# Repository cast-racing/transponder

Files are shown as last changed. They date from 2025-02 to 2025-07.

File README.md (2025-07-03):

# Transponder

Transponder between cars for the Indy Autonomous Challenge.

Features
- Arduino based
- ROS2 node example
- Powered via PoE

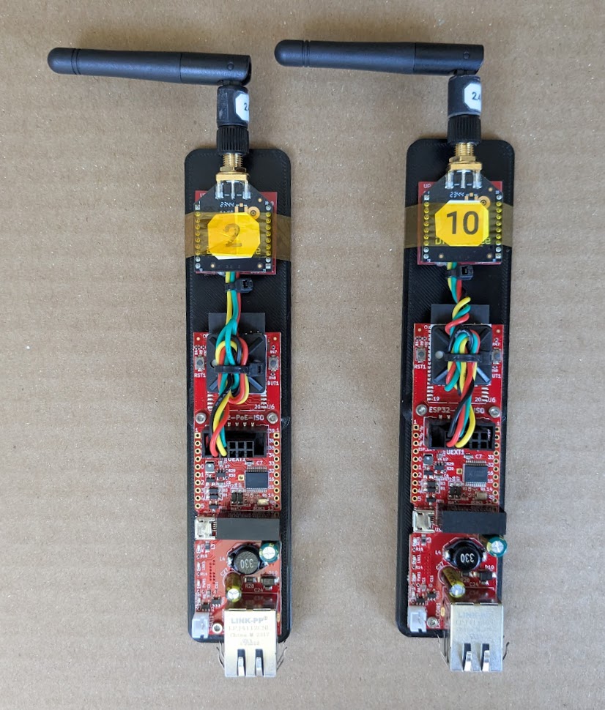
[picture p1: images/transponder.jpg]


## Theory of Operation
The ESP32-PoE-ISO listens to UDP packets published from the ROS2 node `transponder2ros_node`.
These are then packaged with a header and a checksum and sent out as serial data over the xbee network to all the available nodes.
The ESP32-PoE-ISO takes any received packets over the xbee network, checks their integrity, and converts them back into UDP packets, and forwards them back to the `transponder2ros_node`.
The node then publishes the data out as a `transponder_msgs::msg::Transponder` onto the ROS2 network.

Each air packet is about 40 bytes long, so the network can handle about `XXXXX, to test in real world conditions` packets/sec between all nodes.
The data format is designed to look like a GPS packet with some additional information, so make sure to read the comments in the `.msg` file to ensure your data is in the correct units (and scales).
All data should be referenced from the centre of the rear axle and the time reference is UTC.

## Installation
### ROS2
All dependencies on the ROS2 side can be installed via rosdep.
From your main workspace folder, run `rosdep install --from-paths src --ignore-src -r -y`.
If you have trouble with finding geographiclibs, debian/ubuntu installs `FindGeographicLib.cmake` in a non-standard location, but this should be covered in the `CMakeLists.txt` file.

### Arduino
The Arduino code is only required to update the transponder firmware.
See the [Arduino README.md](arduino/README.md) for installation instructions.

### XBee
[XTCU](https://www.digi.com/products/embedded-systems/digi-xbee/digi-xbee-tools/xctu) is used to configure the XBee.  This should only be required once.

## Component Setup
See the individual README.md files in each folder for more information - [ESP32-PoE-ISO (Arduino)](arduino/README.md) / [ROS](ros/README.md) / [XBee](xbee/README.md) / [Hardware](hardware/README.md).

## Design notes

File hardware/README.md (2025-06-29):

# Transponder Hardware

## Bill of Materials
- Compute
  - Olimex ESP32-PoE-ISO
    - https://www.digikey.com/en/products/detail/olimex-ltd/ESP32-POE-ISO/10258716
- Radio
  - Xbee radio
    - https://www.digikey.com/en/products/detail/digi/XB3-24Z8ST/8130935
  - Xbee breakout
    - https://www.digikey.com/en/products/detail/sparkfun-electronics/BOB-08276/5318741
  - Xbee headers
    - https://www.digikey.com/en/products/detail/adafruit-industries-llc/366/5629440
  - Xbee to USB breakout (recommended for programming Xbees)
    - https://www.digikey.com/en/products/detail/sparkfun-electronics/11812/5762455
- Antennas
  - Antenna (small)
    - https://www.digikey.com/en/products/detail/te-connectivity-linx/ANT-2-4-LCW-RPS/9607800
  - Antenna (large)
    - https://www.digikey.com/en/products/detail/taoglas-limited/FW-24-SMA-M/7035228
- Extension Cables
  - 250 mm (9.8") RP-SMA to RP-SMA
    - https://www.digikey.com/en/products/detail/sparkfun-electronics/22037/21443079
  - 1 m (3'3") RP-SMA to RP-SMA
    - https://www.digikey.com/en/products/detail/sparkfun-electronics/22036/21443073

## Wiring
26 AWG is a good choice for wiring guage, however down to 30 AWG will work fine too.
You can use 0.1" headers (female dupont) for connecting to the ESP32-PoE-ISO.

| Colour  | Voltage | ESP32-PoE-ISO | XBee |
| --- | --- | --- | ---- |
| Red | 3V3 | +3.3V (Pin 1) | VCC  |
| Black | GND | GND (Pin 2) | GND  |
| Yellow  | 3V3 | U1TXD (Pin 3) | DIN  |
| Green | 3V3 | U1RXD (Pin 4) | DOUT |

> **Warning:** Different XBee breakout boards may take different voltages in or have slightly different locations for each of the pins.
Make sure to double check your wiring and use a multimeter before first connecting everything.

Finally, make sure to hotglue down the wires to help load alleviate the solder joints.

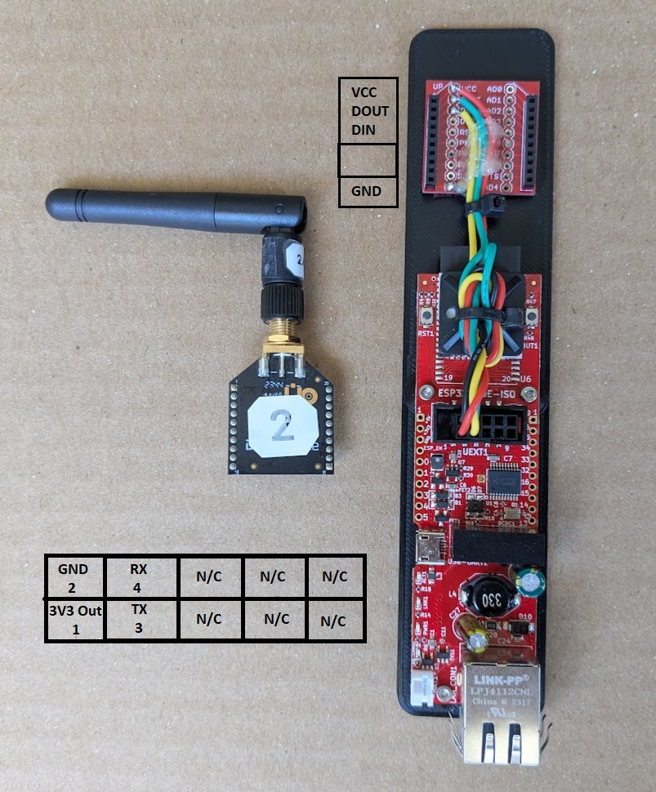
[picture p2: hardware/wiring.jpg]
wiring


## Assembly
The attached STL (Solidworks files included) can be 3D printed to give a mount that can be used to join the parts together.
- Three [M2x6 socket head cap screws](https://www.mcmaster.com/91292a831/) are used for mounting the ESP32-PoE-ISO to the board.
  - You could probably also use double-sided tape and a cable tie, but things might get a little warm.
- Double-sided tape is used to mount the XBee to the board
  - Hold the XBee to the board by wrapping tape around.
- Clean up your cables.
  - A 0.75" x 0.75" cable tie mount works well
  - Don't pull the cables too tightly

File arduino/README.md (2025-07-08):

# Transponder (Arduino)

The ESP32-PoE-ISO is programmed using Arduino, and is required to set up the IP addresses.  Flashing should only be required once and then only during message version updates.

## Installation
### Linux
- Download Arduino CLI (or use an existing Arduino install)
  - Follow the instructions at https://arduino.github.io/arduino-cli/1.2/installation/, or,
  - `curl -fsSL https://raw.githubusercontent.com/arduino/arduino-cli/master/install.sh | sh`
    - Move the file `bin/arduino-cli` to `/usr/bin`
- Install board support (search cores with  `arduino-cli board search olimex`)
  - `arduino-cli core update-index`
  - `arduino-cli config set network.connection_timeout 600s`
  - `arduino-cli core install esp32:esp32`

### Windows
Windows doesn't support arduino-cli, so there's a little more manual setup requried.
- Download Arduino IDE from https://www.arduino.cc/en/software
- Install the ESP32 Core
  - `Tools > Board > Board Manager` and search for esp32
  - Install `esp32 by Espressif Systems`
- Under `Select Board > Select Other Board and Port`
  -  Boards: `OLIMEX ESP32-POE-ISO`
  -  Ports: Select the correct port for the Transponder (plugged in via USB)
-  Modify the code as below, then upload using the arrow in the circle (top left-hand corner near the tick).

You can see the debug messages through the Serial Monitor
- `Tools > Serial Monitor`

## Flashing the Firmware
- Change the network settings in `arduino/transponder/transponder.ino` to match your network
  - Comment / uncomment the `#define` at the top of the script to match your setup
    - `#define TRANSPONDER_IP "10.42.7.61"` is the IP address of your transponder
    - `#define COMPUTER_IP "10.42.7.4"` is the IP address of your computer's network interface
    - If your car is not listed, submit a PR to get it added
- Upload using the script `./compile_and_upload`.  Check the devices match (defaults to `/dev/ttyUSB0`)
  - Alternatively use the Arduino IDE and upload as `OLIMEX ESP32-POE-ISO` board type.
    - Requires the [Arduino-ESP32 package](https://docs.espressif.com/projects/arduino-esp32/en/latest/installing.html).
- The USB connection provides debug information at a baud rate of 115200 including IPs and received information.

## Debugging
The main way to debug is to get the transponder to print when it receives packets from either the UDP or XBee ports.
These messages can be viewed by connecting to the uUSB port on the transponder and connecting via a serial port at 115200 baud.
On a heavily loaded network, the debugging will likely overload the serial port, so the messages are disabled by default.
To enable the debug messages, set `const bool print_debug_ = 0;` to `1` in `transponder.ino`, an re-upload the firmware.

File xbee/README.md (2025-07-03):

# XBee

The XBee is used to communicate between the nodes.

## Configuration
- Download XCTU from
- Connect to the xbee, and apply the profile in `xbee/iac_default.pro`.
  - Update the parameters and the firmware.  If it doesn't update the firmware, apply the settings, and upload the profile again. 
  - Remember to click the `Write` button!
- Power cycle the XBee.  The baud rate will be switched to 57600 baud.
- Connect again and set the `Node Identifier` to the car number for easy remote identification.
  - Remember to click the `Write` button.

## Images
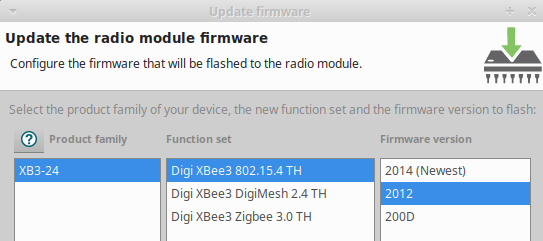
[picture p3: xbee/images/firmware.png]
firmware


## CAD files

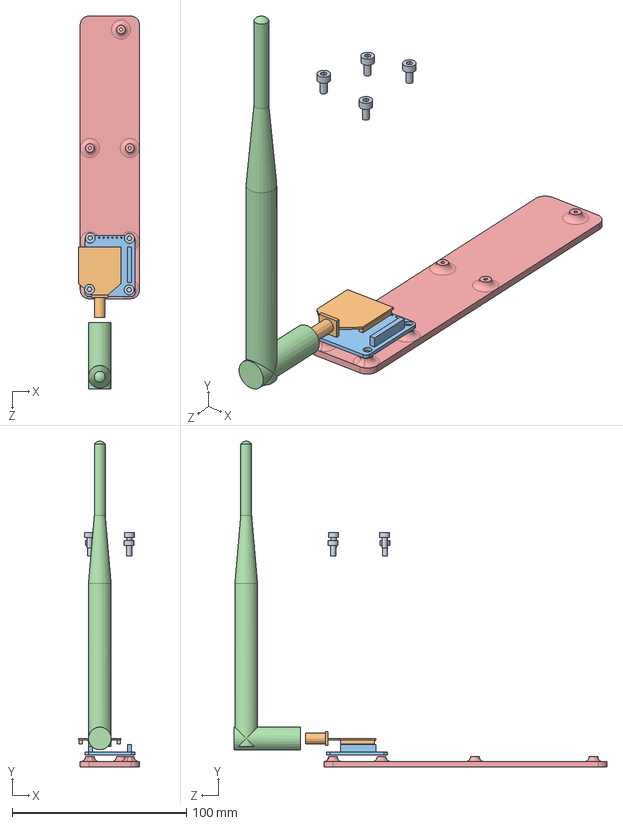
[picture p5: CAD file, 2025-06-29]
hardware/cad/transponder_assembly.SLDASM
35.0 x 186.7 x 213.8 mm
esp32-poe-iso_mount
2.4GHz_antenna_long
xbee_explorer_adaptor
xbee3
M3x6 x 4

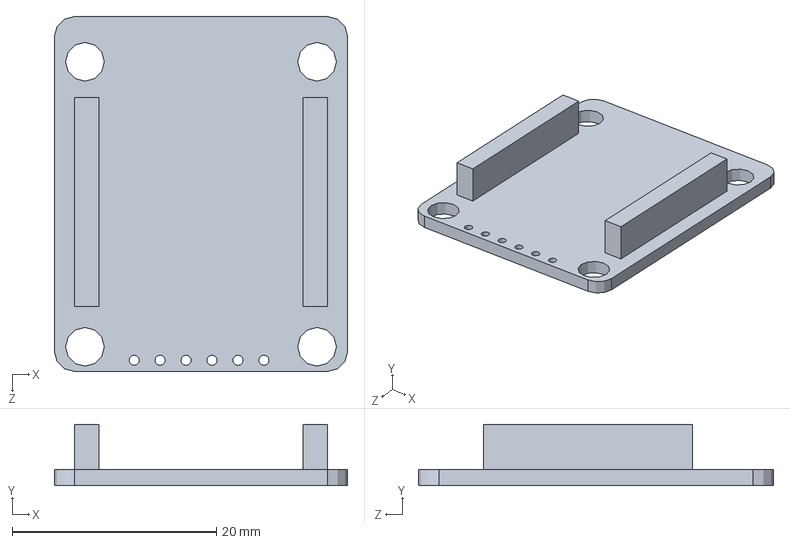
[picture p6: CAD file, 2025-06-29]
hardware/cad/xbee_explorer_adaptor.SLDPRT
28.8 x 5.99 x 34.8 mm

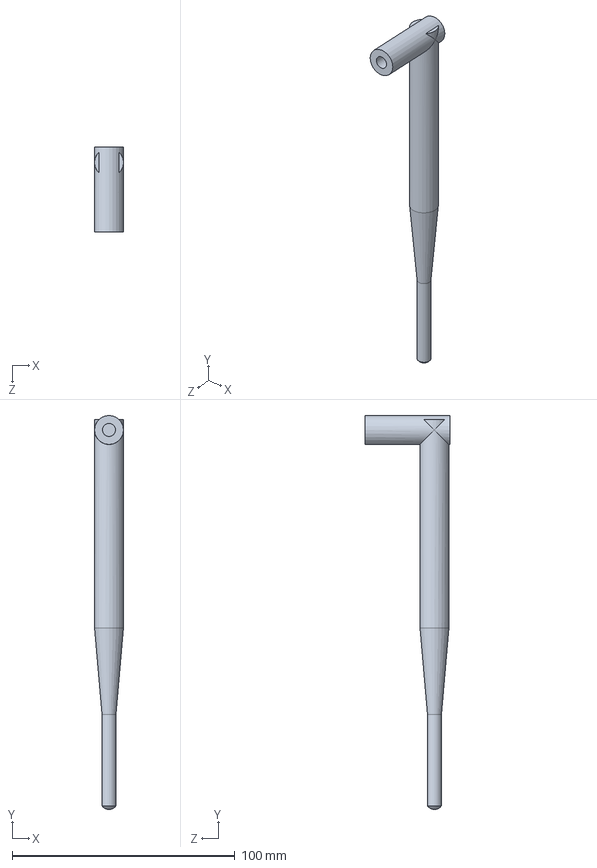
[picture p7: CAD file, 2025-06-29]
hardware/cad/2.4GHz_antenna_long.SLDPRT
13.0 x 176.9 x 38.2 mm

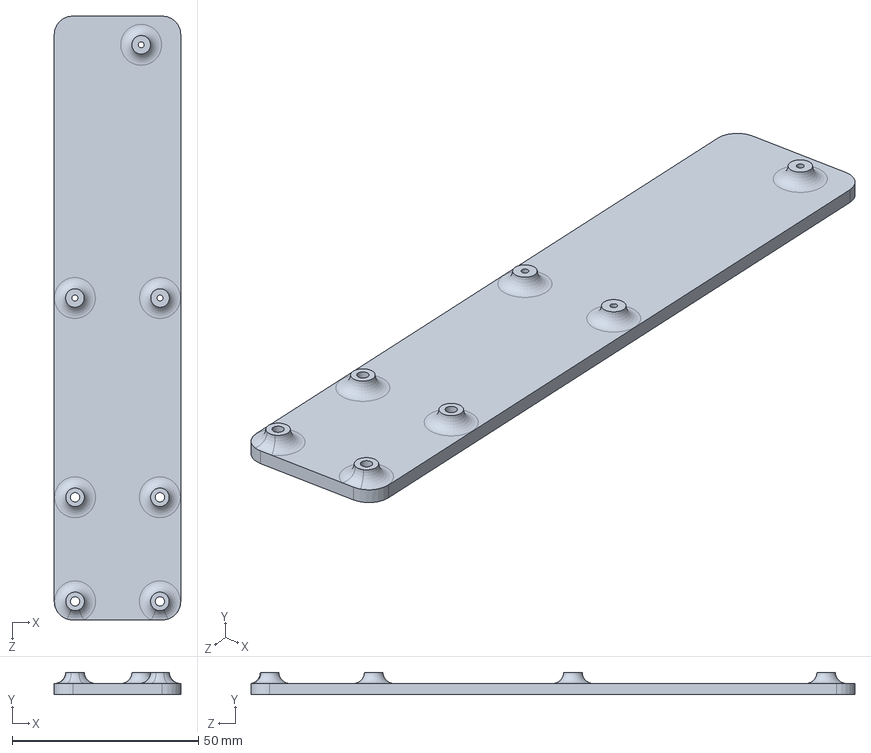
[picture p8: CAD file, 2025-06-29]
hardware/cad/esp32-poe-iso_mount.SLDPRT
34.0 x 6.00 x 162.1 mm

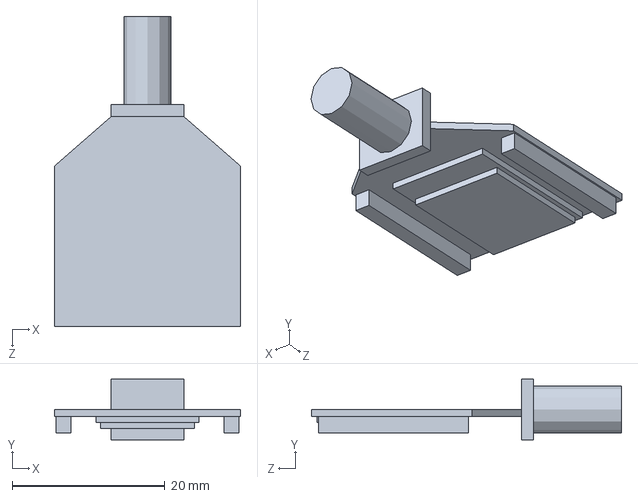
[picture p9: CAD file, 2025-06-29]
hardware/cad/xbee3.SLDPRT
24.4 x 7.93 x 40.6 mm

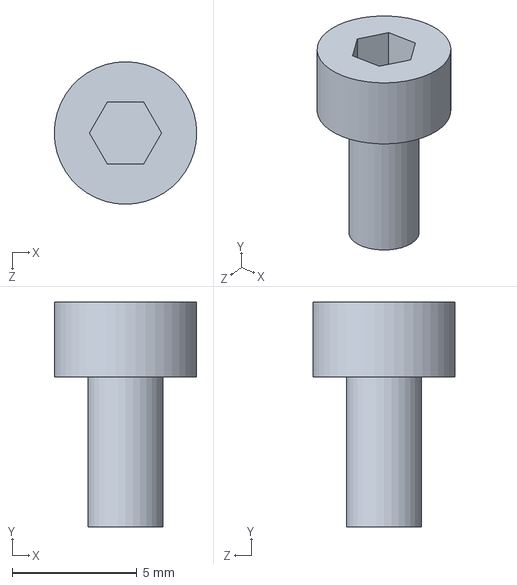
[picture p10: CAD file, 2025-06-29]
hardware/cad/M3x6.SLDPRT
5.70 x 9.00 x 5.70 mm

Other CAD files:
hardware/cad/esp32-poe-iso_mount.STL

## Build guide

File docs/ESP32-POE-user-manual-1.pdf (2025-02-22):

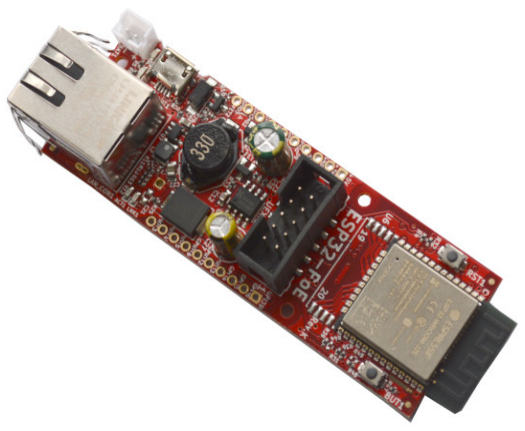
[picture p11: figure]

# ES32-POE ESP32-POE-ISO

# User Manual

Document revision 2.2.

## June 2024

# www.olimex.com

## Table of Contents

## 1. Introduction to ESP32-POE and ESP32-POE-ISO

ESP32-PoE (https://www.olimex.com/Products/IoT/ESP32/ESP32-POE/open-source-hardware) and ESP32-PoE-ISO (https://www.olimex.com/Products/IoT/ESP32/ESP32-POE-ISO/open-source-hardware) are ESP32-powered Wi-Fi/Bluetooth/Ethernet development boards with Power-Over-Ethernet feature. The boards are the perfect addition to any project that requires extra connectivity.
The PoE is currently handled by TPS2375/6 chip (Si3402-B in older revisions) that is IEEE 802.3af-compliant, including pre-standard (legacy) PoE support.
The PoE powering requires at least 37V DC to operate successfully. The board can takes power from the Ethernet cable and can be expanded with sensors and more. Perfect solution for Internet-of-Things projects.
Both ESP32-POE and ESP32-POE-ISO are mature, popular, and well-known products, with wide software support.
+ Important notice: ESP32-PoE (https://www.olimex.com/Products/IoT/ESP32/ESP32-POE/open-source-hardware) has no galvano isolation of Ethernet's power supply, when you program the board via the micro USB connector the Ethernet cable should be disconnected (if you have power over the Ethernet enabled)! Consider using Olimex USB-ISO (https://www.olimex.com/Products/USB-Modules/USB-ISO/) to protect your computer and board from accidental short circuits. Also consider using Olimex ESP32-PoE-ISO (https://www.olimex.com/Products/IoT/ESP32/ESP32-POE-ISO/open-source-hardware) board instead since it is insulated.

## 1.1. ESP32-POE features

- ESP32-WROOM-32E module WiFi + Bluetooth ® + Bluetooth LE module from Espressif Inc (ESP32-WROOM-32UE or ESP32-WROVER-E/IE depending on variant)
- ESP32-WROOM-32E/UE have 4MB flash and 520 KB SRAM
- ESP32-WROVER-E/IE have 4MB Flash 520KB SRAM and 8MB PSRAM
- High reliable industrial grade (-40+85C) variant available (-IND)
- CE-RED and LVD certification
- Original design by OLIMEX Ltd
- Power Over Ethernet negotiation circuit, 802.3-compliant, with minimum operating voltage of 37VDC
- DC-DC converter with 3A at 5V output
- Li-Po battery charger and connector
- Battery level monitor pin on ADC
- External power supply detection pin on ADC
- UEXT connector (https://www.olimex.com/Products/Modules/UEXT/)
- User button
- Reset button
- Micro USB with programmer for ESP32 programming
- MicroSD card
- Two extension connectors 0.1" step spaced at 1"
- PCB dimensions: (80 x 28)mm ~ (3.15 x 1.1)"

## 1.2. ESP32-POE-ISO features

- ESP32-WROOM-32E WiFi + Bluetooth ® + Bluetooth LE module by Espressif Inc (ESP32-WROOM-32UE or ESP32-WROVER-E/IE depending on variant)
- ESP32-WROOM-32E and ESP32-WROOM-32UE have 4MB flash and 520 KB SRAM
- ESP32-WROVER-E/IE have 4MB Flash 520KB SRAM and 8MB PSRAM
- Power Over Ethernet negotiation circuit 802.3 compliant, with minimum operating voltage of 35VDC
- High reliable industrial grade -40+85C available (-IND)
- CE-RED and LVD certification
- Original design by OLIMEX Ltd
- Low power design – 200uA consumption in deep sleep
- Ethernet 100Mb interface with IEEE 802.3 PoE support
- 3000VDC galvanic insulation between the PoE Ethernet part and board's power supply circuit Micro USB connector for ESP32 programming
- MicroSD card working in 1 bit mode
- LiPo battery charger with LiPo battery connector
- Battery level monitor pin on ADC
- External power supply detection pin on ADC
- DC-DC 2W 5V/400mA
- UEXT connector (https://www.olimex.com/Products/Modules/UEXT/)
- User button
- Reset button
- Two extension connectors, 0.1" step spaced at 1"
- PCB dimensions: (98x28)mm ~ (3.8x1)"

## 1.3. PoE standard

ESP32-POE and ESP32-POE-ISO are compliant with the IEEE 802.3af PoE standard and provide up to 15.4 W of DC power (minimum 37V DC and 350 mA). Only 12.95 W are assured to be available at the powered device as some power dissipates in the cable.

ESP32-POE-ISO has 2W DC-DC 5V-5V insulation converter which prevents electrical influence between different sources of power but limits the power usage to 2W only!

## 1.4. The difference between ESP32-POE and ESP32-POE-ISO:

ESP32-POE is not galvanically isolated which means that it’s not safe to connect it to other devices which use non isolated power supply while it is powered. It should have only one power supply and one ground attached to it at a time.
+ This means YOU SHOULD NOT CONNECT ESP32-POE to computer’s USB port while it is powered by Ethernet POE!!! If you connect USB while ESP32-POE is powered by Ethernet you will damage the board or your computer or both. This will also void the warranty!

ESP32-POE-ISO, on the other hand comes with 3000VDC galvanic insulation between the Ethernet POE part and ESP32 power supply, so there is no problem to connect to USB and program or debug while the board is also powered from a PoE source.

## 1.5. The differences between different variants of ESP32-POE and ESP32-POE-ISO:

ESP32-POE (https://www.olimex.com/Products/IoT/ESP32/ESP32-POE/open-source-hardware) and ESP32-POE-ISO (https://www.olimex.com/Products/IoT/ESP32/ESP32-POE-ISO/open-source-hardware) are the base versions with ESP32-WROOM module with 4MB flash memory and nothing extra.

ESP32-POE-EA (https://www.olimex.com/Products/IoT/ESP32/ESP32-POE-EA/open-source-hardware) and ESP32-POE-ISO-EA (https://www.olimex.com/Products/IoT/ESP32/ESP32-POE-ISO-EA/open-source-hardware) have ESP32-WROOM-32UE module with U.FL connector and external antenna attached.

ESP32-POE-IND (https://www.olimex.com/Products/IoT/ESP32/ESP32-POE-IND/open-source-hardware) and ESP32-POE-EA-IND (https://www.olimex.com/Products/IoT/ESP32/ESP32-POE-EA-IND/open-source-hardware) and ESP32-POE-ISO-IND (https://www.olimex.com/Products/IoT/ESP32/ESP32-POE-ISO-IND) and ESP32-POE-ISO-EA-IND (https://www.olimex.com/Products/IoT/ESP32/ESP32-POE-ISO-EA-IND) use industrial grade components suitable for -40+85C operating temperature.

ESP32-POE-WROVER (https://www.olimex.com/Products/IoT/ESP32/ESP32-POE-WROVER/open-source-hardware) and ESP32-POE-ISO-WROVER (https://www.olimex.com/Products/IoT/ESP32/ESP32-POE-ISO-WROVER) comes with ESP32-WROVER-E chip with 4MB flash and 8MB PSRAM, while ESP32-POE-WROVER-EA (https://www.olimex.com/Products/IoT/ESP32/ESP32-POE-WROVER-EA/open-source-hardware) and ESP32-POE-ISO-WROVER-EA (https://www.olimex.com/Products/IoT/ESP32/ESP32-POE-ISO-WROVER-EA) have a WROVER module with extra U.FL connector and external antenna attached.

ESP32-POE-16MB, (https://www.olimex.com/Products/IoT/ESP32/ESP32-POE-16MB/open-source-hardware) ESP32-POE-EA-16MB, (https://www.olimex.com/Products/IoT/ESP32/ESP32-POE-EA-16MB/open-source-hardware) ESP32-POE-ISO-16MB (https://www.olimex.com/Products/IoT/ESP32/ESP32-POE-ISO-16MB/open-source-hardware) and ESP32-POE-ISO-EA-16MB (https://www.olimex.com/Products/IoT/ESP32/ESP32-POE-ISO-EA-16MB/open-source-hardware) feature ESP32-WROOM with 16MB flash memory (as opposed to 4MB).

Features table:

Name/Features | ESP32 module | Flash size, MB | External antenna | Industrial range | PSRAM, MB | Isolated POE
ESP32-POE | ESP32-WROOM-32E-N4 | 4 | - | - | - | -
ESP32-POE-16MB | ESP32-WROOM-32E-N16 | 16 | - | - | - | -
ESP32-POE-EA | ESP32-WROOM-32UE | 4 | Y | - | - | -
ESP32-POE-EA-16MB | ESP32-WROOM-32E-N16 | 16 | Y | - | - | -
ESP32-POE-EA-IND | ESP32-WROOM-32UE | 4 | Y | Y | - | -
ESP32-POE-IND | ESP32-WROOM-32E-N4 | 4 | - | Y | - | -
ESP32-POE-WROVER | ESP32-WROVER-E | 4 | - | - | 8 | -
ESP32-POE-WROVER-EA | ESP32-WROVER-IE | 4 | Y | - | 8 | -
ESP32-POE-ISO | ESP32-WROOM-32E-N4 | 4 | - | - | - | Y
ESP32-POE-ISO-16MB | ESP32-WROOM-32E-N16 | 16 | - | - | - | Y
ESP32-POE-ISO-16MB-IND | ESP32-WROOM-32E-N16 | 16 | - | Y | - | Y
ESP32-POE-ISO-EA | ESP32-WROOM-32UE | 4 | Y | - | - | Y
ESP32-POE-ISO-EA-16MB | ESP32-WROOM-32UE-N16 | 16 | Y | - | - | Y
ESP32-POE-ISO-EA-IND | ESP32-WROOM-32UE | 4 | Y | Y | - | Y
ESP32-POE-ISO-IND | ESP32-WROOM-32E-N4 | 4 | - | Y | - | Y
ESP32-POE-ISO-WROVER | ESP32-WROVER-E | 4 | - | - | 8 | Y
ESP32-POE-ISO-WROVER-EA | ESP32-WROVER-IE | 4 | Y | - | 8 | Y

+ WROVER module uses two extra ESP32 pins for the PSRAM and these pins can’t be used for other purposes. This is important especially if you switch from regular version to WROVER version. This is easily noticeable in the middle of the schematic. GPIO16 and GPIO17 are used by the PSRAM, so GPIO17 that was used for Ethernet clock was replaced by GPIO0 and GPIO16 was replaced by GPIO33. You should do the requires software changes in your code if you switch from ESP32-POE to WROVER version.

## 1.6. Order codes for ESP32-POE and accessories:

ESP32-POE (https://www.olimex.com/Products/IoT/ESP32/ESP32-POE/open-source-hardware) | commercial grade 0-70C board with internal antenna
ESP32-POE-16MB (https://www.olimex.com/Products/IoT/ESP32/ESP32-POE-16MB/open-source-hardware) | commercial grade 0-70C board with internal antenna and 16MB flash
ESP32-POE-EA (https://www.olimex.com/Products/IoT/ESP32/ESP32-POE-EA/open-source-hardware) | commercial grade 0-70C board with external antenna
ESP32-POE-EA-16MB (https://www.olimex.com/Products/IoT/ESP32/ESP32-POE-EA-16MB/open-source-hardware) | commercial grade 0-70C board with external antenna and 16MB flash
ESP32-POE-IND (https://www.olimex.com/Products/IoT/ESP32/ESP32-POE-IND/open-source-hardware) | industrial grade -40+85C board with internal antenna
ESP32-POE-EA-IND (https://www.olimex.com/Products/IoT/ESP32/ESP32-POE-EA-IND/open-source-hardware) | industrial grade -40+85C board with external antenna
ESP32-POE-WROVER (https://www.olimex.com/Products/IoT/ESP32/ESP32-POE-WROVER/open-source-hardware) | commercial grade 0-70C board with 8MB PSRAM and internal antenna
ESP32-POE-WROVER-EA (https://www.olimex.com/Products/IoT/ESP32/ESP32-POE-WROVER-EA/open-source-hardware) commercial grade 0-70C board with 8MB PSRAM and external antenna

BATTERY-LIPO1400mAh (https://www.olimex.com/Products/Power/Lipo-battery/BATTERY-LIPO1400mAh/) Lipo battery 3.7V 1400mAh – note these batteries can be shipped only
| by ground so we can deliver only to EU destinations.
UEXT modules (https://www.olimex.com/Products/Modules/) | Different sensors, relays, LCDs, RTC, GSM, GPS, accessories which can be connected to UEXT connector

## 1.7. Order codes for ESP32-POE-ISO and accessories:

ESP32-POE- (https://www.olimex.com/Products/IoT/ESP32/ESP32-POE-ISO/open-source-hardware) ISO (https://www.olimex.com/Products/IoT/ESP32/ESP32-POE-ISO/open-source-hardware) | commercial grade 0-70C board with internal antenna
ESP32-POE-ISO-16MB (https://www.olimex.com/Products/IoT/ESP32/ESP32-POE-ISO-16MB/open-source-hardware) | commercial grade 0-70C board with internal antenna and 16MB flash
ESP32-POE-ISO-16MB-IND (https://www.olimex.com/Products/IoT/ESP32/ESP32-POE-ISO-16MB-IND/open-source-hardware) | industrial grade -40+85C board with internal antenna and 16MB flash
ESP32-POE-ISO-EA (https://www.olimex.com/Products/IoT/ESP32/ESP32-POE-ISO-EA/open-source-hardware) | commercial grade 0-70C board with external antenna
ESP32-POE-ISO-EA-16MB (https://www.olimex.com/Products/IoT/ESP32/ESP32-POE-ISO-EA-16MB/open-source-hardware) | commercial grade 0-70C board with external antenna and 16MB flash
ESP32-POE- (https://www.olimex.com/Products/IoT/ESP32/ESP32-POE-ISO-IND/open-source-hardware) ISO (https://www.olimex.com/Products/IoT/ESP32/ESP32-POE-ISO-IND/open-source-hardware) -IND (https://www.olimex.com/Products/IoT/ESP32/ESP32-POE-ISO-IND/open-source-hardware) | industrial grade -40+85C board with internal antenna
ESP32-POE- (https://www.olimex.com/Products/IoT/ESP32/ESP32-POE-ISO-EA-IND/open-source-hardware) ISO- (https://www.olimex.com/Products/IoT/ESP32/ESP32-POE-ISO-EA-IND/open-source-hardware) EA-IND (https://www.olimex.com/Products/IoT/ESP32/ESP32-POE-ISO-EA-IND/open-source-hardware) | industrial grade -40+85C board with external antenna
ESP32-POE- (https://www.olimex.com/Products/IoT/ESP32/ESP32-POE-ISO-WROVER/open-source-hardware) ISO- (https://www.olimex.com/Products/IoT/ESP32/ESP32-POE-ISO-WROVER/open-source-hardware) WROVER (https://www.olimex.com/Products/IoT/ESP32/ESP32-POE-ISO-WROVER/open-source-hardware) | commercial grade 0-70C board with 8MB PSRAM, internal antenna
ESP32-POE- (https://www.olimex.com/Products/IoT/ESP32/ESP32-POE-ISO-WROVER-EA/open-source-hardware) ISO- (https://www.olimex.com/Products/IoT/ESP32/ESP32-POE-ISO-WROVER-EA/open-source-hardware) WROVER-EA (https://www.olimex.com/Products/IoT/ESP32/ESP32-POE-ISO-WROVER-EA/open-source-hardware) commercial grade 0-70C board with 8MB PSRAM, external antenna
BATTERY-LIPO1400mAh (https://www.olimex.com/Products/Power/Lipo-battery/BATTERY-LIPO1400mAh/) | Lipo battery 3.7V 1400mAh – note these batteries can be shipped only by ground so we can deliver only to EU destinations.
UEXT modules (https://www.olimex.com/Products/Modules/) | different sensors, relays, LCDs, RTC, GSM, GPS, accessories which can be connected to UEXT connector

## 2. HARDWARE

## 2.1. ESP32-POE layout:

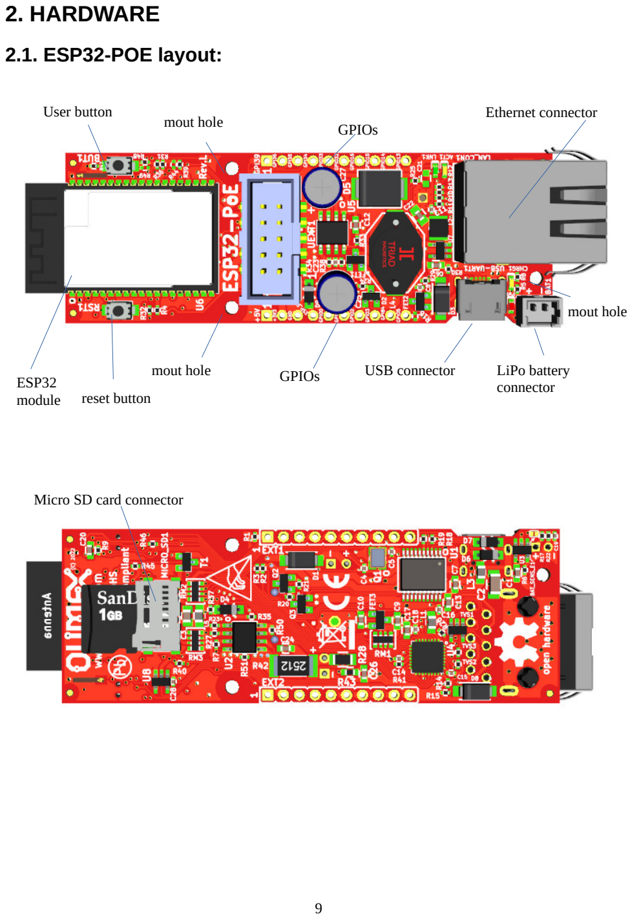
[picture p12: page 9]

User button | mout hole

ESP32
module reset button

mout hole

GPIOs

GPIOs USB connector

Ethernet connector

LiPo battery
connector

mout hole

Micro SD card connector

## 2.2. ESP32-POE GPIOs:

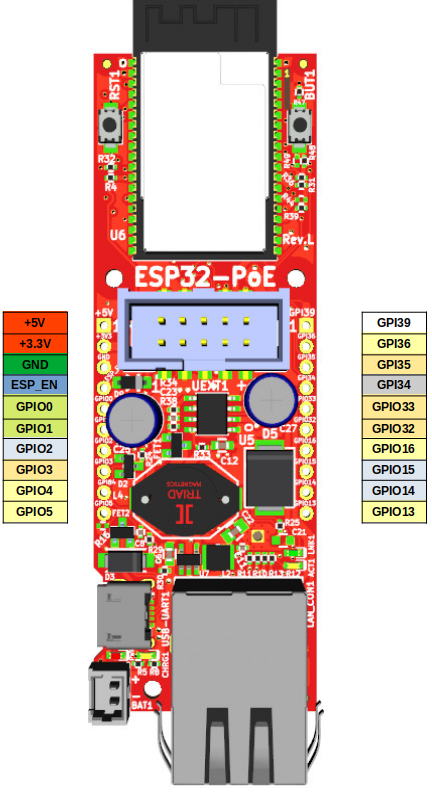
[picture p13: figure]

POWER SUPPLY pads:
+5V 1. Can be input and output; if you use it as input make sure no other 5V sourcesa re applied to the board (having Li-Po battery is OK);
2. When the board is attached to USB or to Ethernet PoE this line can be used ONLY as output
| to power attached peripherals;
3. If you want to use as input i.e. to feed power from external 5V to this line make sure that
| board is not connected to USB!
4. When you use the 5V line as output to power external devices it can provide up to 0.8A @ 5V
| (i.e. 4W) maximum. This includes the 3.3V power output. The combined power draw of +5V output and +3.3V output must not exceed 4W!

+3.3V output which can source up to 0.5A @ 3.3V i.e. (1.65W) Make sure the combined power
| sourced from +3.3V and +5V does not exceed 4W!
GND Ground, the board has common ground.

GPIO pads:
ESP_EN resets the ESP32 module
GPIO0, GPIO2 are boot mode bootstrap pins make sure they are properly configured during power up GPIO1, GPIO3 are used for USB programming, they can be freed up if you won’t further program the boar via USB
GPIO2, GPIO14, GPIO15 are used for the SD-card, if no SD card is preset they are free to use GPIO2, GPIO4, GPIO5, GPIO13, GPIO14, GPIO15, GPIO16, GPIO36 are shared on both UEXT and EXT headers so if you use them on the one connector do not use them at the other
GPI39 is connected to measure external power supply voltage
GPI34 is connected to user button and has 10K pullup
GPI35 is free to use by default but may be connected to measure the LiPo battery voltage if you close BAT_SENS_E1 jumper
+ESP32-POE-WROVER and ESP32-POE-WROVER-EA have no GPIO16 or GPIO17 led out, since they are used for the PSRAM. These are replaced by GPIO33 and GPIO0. GPIO17 being replaced by GPIO0 is crucial for the Ethernet connectivity, since GPIO17/GPIO0 is Ethernet clock out. Make sure to use new assignments in your software if your board variant comes with the WROVER chip.
The ESP32 chip has very advanced multiplexing and you can define any free GPIO pin for I2C, UART, SPI operation as long as you are within the maximum supported (some penalties to SPI's maximum frequency apply, when not using the dedicated pins). Notice that some ESP32 pins can only be inputs. Defining pins is for another job is purely software effort.
For further analysis of pins it is highly recommended to check on the schematic.

## 2.3. ESP32-POE-ISO GPIOs:

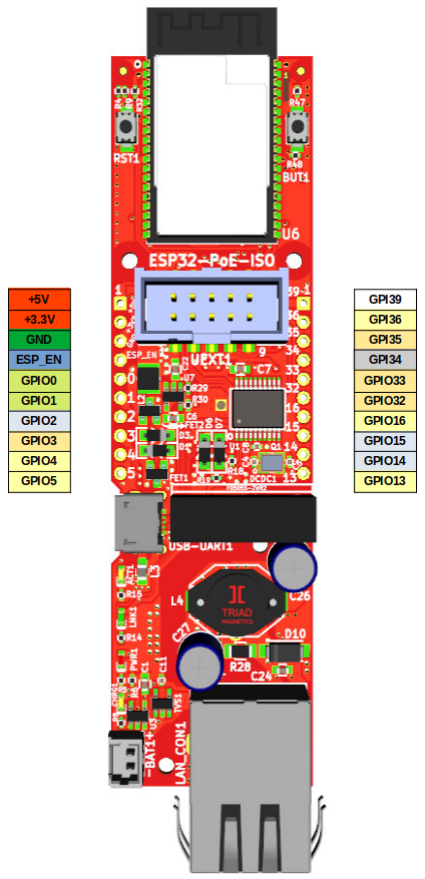
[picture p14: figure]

POWER SUPPLY pads:
+5V 1. Can be used as either input and output. f you use it as input make sure no other 5V source is applied to the board (Li-Po battery is OK);
2. When the board is connected to USB or to Ethernet PoE this line can be used as output and
| power supplement electronic
3. if you want to use as input i.e. to feed power from external 5V to this line make sure board is
| not connected to USB!
4. when you use as output i.e. you feed external electronics from it up to 0.2A @ 5V (i.e. 1W)
| can be sourced maximum. This includes the 3.3V power output. The combined power must not exceed 1W.

+3.3V output which can source up to 0.33A @ 3.3V i.e. (1W) - make sure the combined power
| sourced from +3.3V and +5V does not exceed 1W
GPIO pads:
ESP_EN resets ESP32 module
GPIO0, GPIO1 are used only during programming, after that are free to use
GPIO2, GPIO14, GPIO15 are used for the SD-card, if no SD card they are free to use
GPIO2, GPIO4, GPIO5, GPIO13, GPIO14, GPIO15, GPIO16, GPIO36 are shared on both UEXT and EXT headers so if you use them on the one connector do not use on the other
GPI39 is connected to measure external power supply voltage;
GPI35 is used for battery measurement of the LiPo battery;
GPI34 is connected to used button and has a 10K pullup resistor.

+ESP32-POE-ISO-WROVER and ESP32-POE-ISO-WROVER-EA have no GPIO16 and GPIO17 led out, since they are used for the PSRAM. GPIO16 is replaced by GPIO33. GPIO17 is replaced by GPIO0, this is important for the Ethernet connectivity, since GPIO17/GPIO0 is Ethernet clock out. Make sure to use new assignments if your board variant comes with the WROVER chip.
The ESP32 chip has very advanced multiplexing and you can define any free GPIO pin for I2C, UART, SPI operation as long as you are within the maximum supported (some penalties to SPI's maximum freqncy apply, when not using the dedicated pins). Notice that some ESP32 pins can only be inputs. Defining pins is for another job is purely software effort.
For further analysis of pins it is highly recommended to check on the schematic.

## 2.4. ESP32-POE(-ISO) schematics

This is an open hardware design made with KiCAD. All design files and exports can be found at our GitHub.

ESP32-POE schematic hardware revision L is at GitHub (https://github.com/OLIMEX/ESP32-POE/tree/master/HARDWARE/ESP32-PoE-hardware-revision-L)
ESP32-POE board revision changes are at GitHub (https://github.com/OLIMEX/ESP32-POE/blob/master/HARDWARE/Revision-changes.txt)

ESP32-POE-ISO schematic revision L is at GitHub (https://github.com/OLIMEX/ESP32-POE-ISO/tree/master/HARDWARE/ESP32-PoE-ISO-Rev.L) ESP32-POE-ISO board revision changes are at GitHub (https://github.com/OLIMEX/ESP32-POE-ISO/blob/master/HARDWARE/Hardware-changes-log.txt)

## 2.5. ESP32-POE(-ISO) power supply

ESP32-POE(-ISO) can be powered by 4 sources:
- Ethernet PoE
- USB-micro connector
- Li-Po battery
- EXT1 pin 1 (+5V) but note that this signal is connected to USB 5V signal so when you power via this EXT1 pin you should not connect the board to the USB!
- The standard power consumption of ESP32-POE(-ISO) is between 50mA and 200mA depending on the operation mode. When using power-down modes and Li-Po battery power it can go down to micro amperes.
- Li-Po battery gets automatically charged with about 100mA when external power supply is present. When the LiPo battery is attached and external power supply is missing internal DCDC step-up converter and switching circuit automatically powers ESP32-POE from the battery. 1400mAh battery will provide about 8 hours of stand alone operation.
+The LiPo battery connector is JST 2.0 mm connector and with Olimex’s battery polarity. If you use batteries from other manufacturers please make PLUS and MINUS are connected properly as you may damage the board!
+ Is it safe to have USB and PoE connected and enabled at the same time? If you are using ESP32-POE or any of its variants – no, it is not safe and should be avoided at all costs. If you are using ESP32-POE-ISO or any of its variants – yes, it is safe to have them both attached and enabled.

### 2.5.1. External power sense feature

This allows to detect when the board has external powering. This is helpful if you want to switch between different power modes depending on whether the board is powered from a battery or external power source. By default the external power sense is enabled and it is available on GPI39!
Refer to this Arduino IDE example to see how you can check for the presence external power and check the battery measurement:
https://github.com/OLIMEX/ESP32-POE/blob/master/SOFTWARE/ARDUINO/ESP32_PoE_PowerReading/ESP32_PoE_PowerReading.ino (https://github.com/OLIMEX/ESP32-POE/blob/master/SOFTWARE/ARDUINO/ESP32_PoE_PowerReading/ESP32_PoE_PowerReading.ino)

### 2.5.2. Battery measurement feature

This allows to measure the Li-Po battery’s voltage. This is helpful so you can evaluate when the battery is going to drain out so you can power off the board safely or switch to more conservative power method. In ESP32-POE and its variants the battery measurement features is disabled by default but you can enabled it by soldering together the pads of STM jumper BAT_SENS_E1 jumper, after closing it – it will be routed to GPI35!
In ESP32-POE-ISO and its variants – the battery measurement is enabled and it is available on GPI35! Refer to this Arduino IDE example to see how you can check for external power and check the battery measurement:
https://github.com/OLIMEX/ESP32-POE/blob/master/SOFTWARE/ARDUINO/ESP32_PoE_PowerReading/ESP32_PoE_PowerReading.ino (https://github.com/OLIMEX/ESP32-POE/blob/master/SOFTWARE/ARDUINO/ESP32_PoE_PowerReading/ESP32_PoE_PowerReading.ino)

## 2.6. UEXT connector:

UEXT connector stands for Universal EXTension connector and typically contains +3.3V, GND, UART, I2C, SPI signals.
UEXT is 0.1” 2.54mm step boxed plastic connector. All signals are with 3.3V levels.

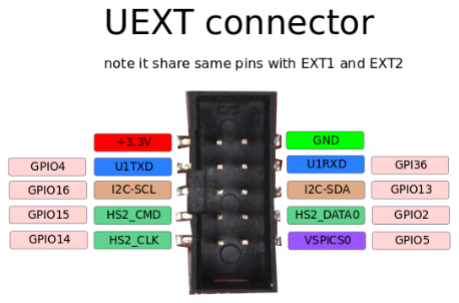
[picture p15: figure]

Olimex has developed number of extension MODULES (https://www.olimex.com/Products/Modules/) compatible with this connector. There are temperature, humidity, pressure, magnetic field, light sensors. Modules with LCDs, LED matrix, relays, Bluetooth, Zigbee, Wi-Fi, GSM, GPS, RFID, RTC, EKG, sensors, and more.

## 2.7. LED description

Board comes with 4 on-board status LEDs. These are not connected to the ESP32 directly and can’t be used as general purpose LEDs.

LED CHRG1 shows whether the Li-Po battery attached to the board is currently charging. When it is off it means that either there is no battery attached or it is already fully charged. Refer to "BL4054/BL4054B" datasheet and check for "CHRGb" port for more detailed information.

LED PWR1 is turned on when there is 5V DC applied to the board. It only actives from external power supply, USB power supply, or PoE powering. It won't turn on when board is powered from a Li-Po battery at BAT1 connector (to conserve energy required to power that LED).

LEDs LNK1 and ACT1 are Ethernet link and activity LEDs. LNK1 is turned on when 100 Mbps speed is detected, and turns off at 10Mbps or less. ACT1 blinks when activity is detected. For more information about their behavior, refer to the manual of "LAN8710A/LAN8710AI" and check the table describing "REGOFF" port (ACT1 is connected to it) and "nINTSEL" port (LNK1 is connected to it).

During USB power up the CHRG1 and PWR1 LEDs should light up.

Important! In order to reduce current consumption the LEDs would remain off when the board is powered from Li-Po battery! Do not count on the LEDs when the board is powered only from a Li-Po battery!

## 3. SOFTWARE:

ESP32-POE and ESP32-POE-ISO are very popular boards and supported by a lot of software tools, among them (there are ready-to-use configs for ESP32-POE and ESP32-POE-ISO):

- Espressif ESP-IDF (https://docs.espressif.com/projects/esp-idf/en/latest/esp32/get-started/)
- Arduino IDE (https://github.com/espressif/arduino-esp32)
- MicroPython (https://micropython.org/download/OLIMEX_ESP32_POE/)
- ESPhome (https://github.com/esphome/bluetooth-proxies/blob/main/olimex-esp32-poe-iso.yaml)
- PlatformIO (https://docs.platformio.org/en/latest/boards/espressif32/esp32-poe.html)

## 3.1. Olimex-made software

We provide some examples for basic functions at our GitHub:

- For Arduino you can find them here:

https://github.com/OLIMEX/ESP32-POE/tree/master/SOFTWARE/ARDUINO

- For ESP-IDF here:

https://github.com/OLIMEX/ESP32-POE/tree/master/SOFTWARE/ESP-IDF

## 4. Frequently asked questions:

- Is it safe to have USB powering and PoE powering connected and enabled at the same time?
- If you are using ESP32-POE or any of its variants – no, it is not safe and should be avoided at all costs.
- If you are using ESP32-POE-ISO or any of its variants – yes, it is safe to have them both enabled.
- Where are I2C, UART, SPI pins exposed?
The ESP32 chip has very advanced multiplexing and you can define any free GPIO pin for I2C, UART, SPI operation as long as you are within the maximum supported (some penalties to SPI's maximum frequency apply, when not using the dedicated pins). Notice that some ESP32 pins can only be inputs. Double check if the pins you want to use are free. Defining pins for another function is a purely software effort.
- I provide 24V to the Ethernet of ESP32-PoE-ISO's but it doesn't seem powered. What is the problem?
TPS2375PW (Si3402) would NOT work with 24V DC. The recommended voltage is 48V DC and the minimum is around 37V DC. For more info refer to TPS2375PW's (Si3402-B's) datasheet.
- I power the board from the Ethernet connector. What current do I have available for additional circuits?
Depends on the board used. If you are using ESP32-POE the PoE circuit can safely provide up to 4W, i.e. 800mA @ 5V. Part of this wattage is used to power the ESP32 module, the battery charger, and other circuits part of the board design; the remaining wattage is available for additional circuits (up to around 600mA). Make sure the total current consumption does not exceed 800mA @ 5V.
If you are using ESP32-POE-ISO the isolated DCDC that we use provides up to 2W, this means 400mA @ 5V, 100mA are reserved for the battery charge (available if no battery is connected) and 100mA are provided for ESP32, which leaves up to 200mA @ 5V for your additional circuits.
- I power the board from the battery connector. The LEDs remain off. Is it broken?
Probably not. This is a low-power design. The LEDs would not turn on when operating on battery to save power. You need other ways to determine if it works or not. For example, something over the serial lines or over the Ethernet (with no PoE enabled else it would get powered from there).

- A specific resistor gets very hot! What is this component? Is it safe? Can I remove it? This is probably the resistor that is required by the IEEE standards. It is used for MPS (maintain power signature). Search online "maintain power signature poe" to get the general idea.

We didn't ensure MPS in the first hardware revisions of the board (e.g. had no resistor in place), but this caused availability problems when using some power saving modes – the board consumed less wattage than PoE equipment can detect, which led to PoE equipment shutting the board off.

If you have soldering experience and the resistor bothers you, you might try desoldering it and see if that effects your setup negatively. Notice that we don't recommend doing so.

- ESP32-PoE and ESP32-POE-ISO don't work well with bauds over 115200. What to do? Some older drivers might have wrong timings, causing worse throughput. Download and install the latest drivers for CH340.
- Help! Ethernet is not working. I use ESP32-POE-WROVER and ESP32-POE-ISO-WROVER
The WROVER module require two addition pins compared to the WROOM module. This required two pin changes – GPIO16 and GPIO17 are used by the PSRAM of the WROVER, so we have replaced GPIO16 with GPIO33 and GPIO17 with GPIO0. The change of GPIO17 affects the Ethernet since it serves as Ethernet clock source. Make sure to replace GPIO17 with GPIO0 in your code or configuration!

## 5. Useful links

The main pages of ESP32-POE and ESP32-POE-ISO are the main hubs for other locations, make sure to first check the product page at our web-site.

ESP32-POE main product page: https://www.olimex.com/Products/IoT/ESP32/ESP32-POE/open-source-hardware

ESP32-POE-ISO main product page: https://www.olimex.com/Products/IoT/ESP32/ESP32-POE-ISO/open-source-hardware

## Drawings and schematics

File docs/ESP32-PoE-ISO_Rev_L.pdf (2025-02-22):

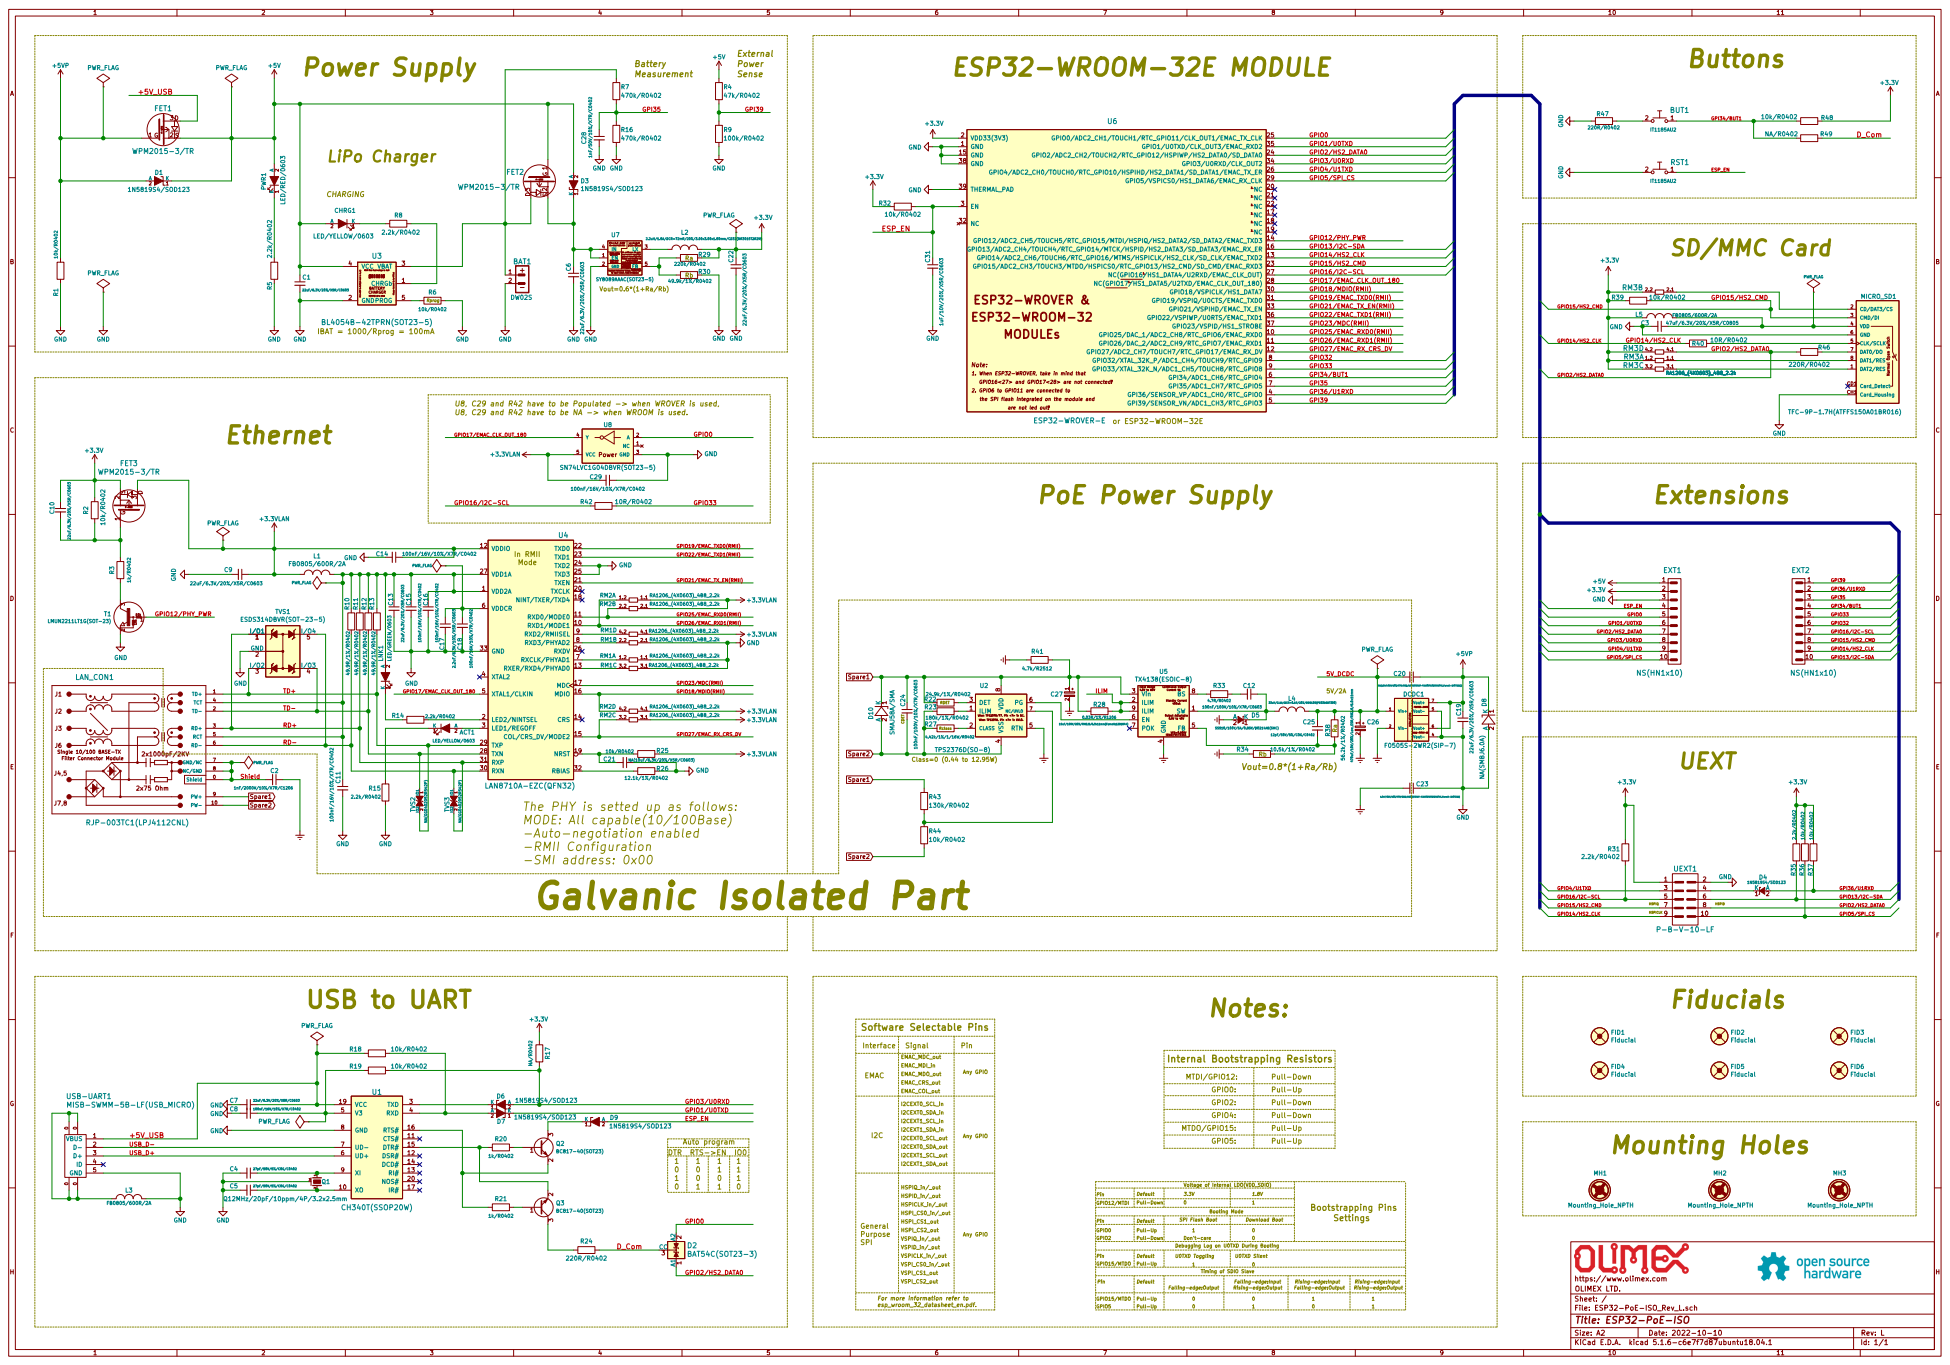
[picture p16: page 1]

2. 2. 2. 2. 2. 2. 2. GPIO6 to GPIO11 are connected to are not led out! ESP32-WROOM-32 ESP32-WROVER &

load current capability! Lx=2.2uH

Do not float. Enable control. FB Input Current, I(FB)=50nA(max) Feedback Reference Voltage, V(REF)=0.6V

1. 1. 1. When ESP32-WROVER, take in mind that

GPIO16<27> and GPIO17<28> are not connected! MODULEs

4 FB 5 EN 6 POK 7 BS 8

Interface The PHY is setted up as follows:
MODE: All capable(10/100Base)
-Auto-negotiation enabled
-RMII Configuration
-SMI address: 0x00

Signal Software Selectable Pins

Auto program
SPI Flash Boot Pull-Up Pull-Down DTR RTS->EN IO0

Falling-edge:Output Pull-Down For more information refer to esp_wroom_32_datasheet_en.pdf.

Id: 1/1 Title: ESP32-PoE-ISO

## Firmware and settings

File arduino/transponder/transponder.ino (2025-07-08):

#include <ETH.h>
#include <WiFi.h>
#include <WiFiUdp.h>

#include "iac_udp_struct.h"
#include "xbee_struct.h"

// Team Defines (comment / uncomment as required)

#define TRANSPONDER_IP "10.42.17.210"  // #7 (Berkeley)
#define COMPUTER_IP "10.42.17.200"

// #define TRANSPONDER_IP "10.42.8.60"  // #8 (Caltech Racer)
// #define COMPUTER_IP "10.42.8.4"

// IP settings
IPAddress local_IP(TRANSPONDER_IP);        // IP Address of the Transponder
IPAddress ip_send_(COMPUTER_IP);           // Destination IP for UDP messages (ROS2 computer)
const unsigned int port_ = 15783;          // UDP port  15783

// Globals
const bool print_debug_ = 0;               // Disable debug prints unless actively using
WiFiUDP udp;

IPAddress gateway(COMPUTER_IP);
IPAddress subnet("255.255.255.0");
IPAddress dns("8.8.8.8");

static bool eth_connected = false;
int32_t last_udp_sec_ = 0;
uint32_t last_udp_nanosec_ = 0;

char buf_[100];   // Buffer for printing strings

// React to Ethernet events:
void WiFiEvent(WiFiEvent_t event)
{
  switch (event) {

    case ARDUINO_EVENT_ETH_START:
      // This will happen during setup, when the Ethernet service starts
      Serial.println("ETH Started");
      ETH.config(local_IP, gateway, subnet, dns);
      //set eth hostname here
      ETH.setHostname("esp32-ethernet");
      break;

    case ARDUINO_EVENT_ETH_CONNECTED:
      // This will happen when the Ethernet cable is plugged 
      Serial.println("ETH Connected");
      break;

    case ARDUINO_EVENT_ETH_GOT_IP:
    // This will happen when we obtain an IP address through DHCP:
      Serial.print("Got an IP Address for ETH MAC: ");
      Serial.println(ETH.macAddress());
      Serial.print("  IPv4: ");
      Serial.println(ETH.localIP());
      if (ETH.fullDuplex()) {
        Serial.print(" FULL_DUPLEX");
      }
      Serial.print("  ");
      Serial.print(ETH.linkSpeed());
      Serial.println("Mbps");
      Serial.print("Sending data to ");
      Serial.println(ip_send_);
      eth_connected = true;
      break;

    case ARDUINO_EVENT_ETH_DISCONNECTED:
      // This will happen when the Ethernet cable is unplugged 
      Serial.println("ETH Disconnected");
      eth_connected = false;
      break;

    case ARDUINO_EVENT_ETH_STOP:
      // This will happen when the ETH interface is stopped but this never happens
      Serial.println("ETH Stopped");
      eth_connected = false;
      break;

    default:
      break;
  }
}

// Initializing everything at start up / after reset:
void setup()
{
  // Wait for the hardware to initialize:
  delay(500);

  // Start debugging serial port
  Serial.begin(115200);
  
  Serial.println("=====================");
  Serial.println("IAC Transponder System");
  Serial.println("TRANSPONDER_IP: "+String(TRANSPONDER_IP)+", COMPUTER_IP: "+String(COMPUTER_IP));
  Serial.println("  Transponder Struct Version: "+String(TRANSPONDER_UDP_STRUCT_VERISON)+", len(XBee Packet): "+String(SIZEOF_XbeePacket)+" bytes");
  Serial.println("=====================");
  Serial.print("Setup...");

  // Start Xbee serial port
  Serial1.begin(57600);
  
  // Add a handler for network events. This is misnamed "WiFi" because the ESP32 is historically WiFi only,
  // but in our case, this will react to Ethernet events.
  Serial.print("Registering event handler for ETH events...");
  WiFi.onEvent(WiFiEvent);
  
  // Starth Ethernet (this does NOT start WiFi at the same time)
  Serial.print("Starting ETH interface...");
  ETH.begin();

  udp.begin(port_);

}

void loop()
{

  process_udp();
  process_xbee();
  // process_debug();  // Code for sending debug packets

}

void process_udp()
{
  // Receive UDP and send to Serial1
  int packetSize = udp.parsePacket();

  if (packetSize == SIZEOF_TransponderUdpPacket)
  {
    // sprintf(buf_,"%8d | UDP packet received (%d bytes)\n",millis(),packetSize); 
    // Serial.print(buf_);

    XbeePacket xbee_packet;

    // Copy UDP packet into Xbee struct
    int len = udp.read(xbee_packet.data.data.raw, SIZEOF_TransponderUdpPacket);

    // Debugging
    if (print_debug_)
    {
      Serial.print("\nReceived from UDP / send XBee\n");
      sprintf(buf_, "    Version: %d\n"    ,xbee_packet.data.data.data.version); Serial.print(buf_);
      sprintf(buf_, "        sec: %d\n"    ,xbee_packet.data.data.data.sec); Serial.print(buf_);
      sprintf(buf_, "    nanosec: %d\n"    ,xbee_packet.data.data.data.nanosec); Serial.print(buf_);
      sprintf(buf_, "        Car: %d\n"    ,xbee_packet.data.data.data.car_id); Serial.print(buf_);
      sprintf(buf_, "        Lat: %11.5f\n",xbee_packet.data.data.data.lat/1e7); Serial.print(buf_);
      sprintf(buf_, "        Lon: %11.5f\n",xbee_packet.data.data.data.lon/1e7); Serial.print(buf_);
      sprintf(buf_, "        Alt: %11.5f\n",xbee_packet.data.data.data.alt/1e3); Serial.print(buf_);
      sprintf(buf_, "    Heading: %5.2f\n" ,xbee_packet.data.data.data.heading/1e2); Serial.print(buf_);
      sprintf(buf_, "        Vel: %5.2f\n" ,xbee_packet.data.data.data.vel/1e2); Serial.print(buf_);
      sprintf(buf_, "      State: %d\n"    ,xbee_packet.data.data.data.state); Serial.print(buf_);
    }

    if (len == SIZEOF_TransponderUdpPacket)
    {
        // Headers
        xbee_packet.data.headerA = xbee_headerA_;
        xbee_packet.data.headerB = xbee_headerB_;

        // Calculate checksum for Xbee struct.  Only use the actual struct data as I loose the headers in the decode
        xbee_packet.data.crc8 = calc_crc8(xbee_packet.data.data.raw, SIZEOF_TransponderUdpPacket);

        // Forward packet out via Serial1
        Serial1.write((uint8_t*)xbee_packet.raw, SIZEOF_XbeePacket);

        // Store the last UTC time a packet was received
        last_udp_sec_ = xbee_packet.data.data.data.sec;
        last_udp_nanosec_ = xbee_packet.data.data.data.nanosec;
    }
    else
    {
      sprintf(buf_,"Read incorrect number of bytes. Got %d, expected %d\n",len,SIZEOF_TransponderUdpPacket); 
      Serial.print(buf_);
    }
  }
  else if (packetSize)
  {

    sprintf(buf_,"Packet size received incorrect. Got %d, expected %d\n",packetSize,SIZEOF_TransponderUdpPacket); 
    Serial.print(buf_);
  }

  // Done
  return;

}

void process_xbee()
{
  
  while (Serial1.available())
  {

    // Send data through state machine
    xbee_state_machine(Serial1.read());

  }

}

void process_debug()
{
  // Send debug data
  static unsigned long t_last = millis();

  if (millis() > t_last + 100)
  {
    send_test_udp();
    t_last = millis();
  } 

  if (0)
  {
    udp.beginPacket(ip_send_, port_);
    udp.print("hello");
    udp.endPacket();
    delay(50);
  }
}

void xbee_state_machine(char x)
{
  if (0)
  {
    sprintf(buf_,"0x%02X ",x);
    Serial.print(buf_);
  }

  static uint state = 0;
  static uint ii = 0;
  static TransponderUdpPacket data;

  switch (state)
  {
    case (0) :
      {
        // Reset variables
        ii = 0;
        // sprintf(buf_,"Looking for headerA : 0x%02X\n",headerA);
        // Serial.print(buf_);

        // Check for header
        if (x == xbee_headerA_)
          state++;
      } 
      break;
    case (1) :
      {
        // sprintf(buf_,"Looking for headerB : 0x%02X\n",headerB);
        // Serial.print(buf_);

        if (x == xbee_headerB_)
        {
          state++;
        }
        else
        {
          state = 0;
        }
      }
      break;
    case (2) :
      {

        data.raw[ii] = x;
        ii++;

        if (ii == SIZEOF_TransponderUdpPacket)
          state++;

      }
      break;
    case (3) :
      {
        // Serial.print("Checking checksum\n");
        uint8_t crc8 = calc_crc8(data.raw, SIZEOF_TransponderUdpPacket);  // Don't include header in checksum
        
        if (x == crc8)
        {
          // Data good, send via UDP
          // Serial.print("Sending UDP packet\n");

          udp.beginPacket(ip_send_, port_);
          udp.write((uint8_t*)data.raw, SIZEOF_TransponderUdpPacket);
          udp.endPacket();

          // Debugging
          if (print_debug_)
          {
            Serial.print("\nReceived from XBee / Send UDP\n");
            sprintf(buf_, "    Version: %d\n"    ,data.data.version); Serial.print(buf_);
            sprintf(buf_, "        sec: %d\n"    ,data.data.sec); Serial.print(buf_);
            sprintf(buf_, "    nanosec: %d\n"    ,data.data.nanosec); Serial.print(buf_);
            sprintf(buf_, "        Car: %d\n"    ,data.data.car_id); Serial.print(buf_);
            sprintf(buf_, "        Lat: %13.8f\n",data.data.lat/1e7); Serial.print(buf_);
            sprintf(buf_, "        Lon: %13.8f\n",data.data.lon/1e7); Serial.print(buf_);
            sprintf(buf_, "        Alt: %8.3f\n" ,data.data.alt/1e3); Serial.print(buf_);
            sprintf(buf_, "    Heading: %5.2f\n" ,data.data.heading/1e2); Serial.print(buf_);
            sprintf(buf_, "        Vel: %5.2f\n" ,data.data.vel/1e2); Serial.print(buf_);
            sprintf(buf_, "      State: %d\n"    ,data.data.state); Serial.print(buf_);
            Serial.print("\n");
          }
        } 
        else
        {
          sprintf(buf_, "Checksum error.  Expected 0x%02X, got 0x%02X\n",crc8,x);
          Serial.print(buf_);
          Serial.println("  If this happens every frame, check the packet versions match");
        }

        // Reset state machine
        state = 0;

      }
      break;
  }
}

void send_test_udp()
{

  static TransponderUdpPacket test_data;

  // Fill the packet with some random stuff
  test_data.data.version = TRANSPONDER_UDP_STRUCT_VERISON;
  test_data.data.sec = last_udp_sec_;
  test_data.data.nanosec = last_udp_nanosec_;
  test_data.data.car_id = 1;

  test_data.data.lat =   362680800 + random(-10, 10);
  test_data.data.lon = -1150181860 + random(-10, 10);
  test_data.data.alt =  142000*1e3 + random(-100, 100);
  test_data.data.heading = random(0,36000);
  test_data.data.vel = random(0,10000);
  test_data.data.state = 3;

  // Send the packet
  udp.beginPacket(ip_send_, port_);
  udp.write((uint8_t*)test_data.raw, SIZEOF_TransponderUdpPacket);
  udp.endPacket();

}

uint8_t calc_crc8(const char* data, size_t len)
{
    // https://www.analog.com/en/resources/technical-articles/
    // understanding-and-using-cyclic-redundancy-checks-with-
    // maxim-1wire-and-ibutton-products.html

    uint8_t crc = 0x00;

    for (size_t ii = 0; ii < len; ii++)
    {
        crc ^= data[ii];

        for (uint8_t jj = 0; jj < 8; jj++)
        {
            if (crc & 0x01)
            {
                crc = (crc >> 1) ^ 0x8C; 
            }
            else
            {
                crc >>= 1;
            }
        }
    }

    // Return crc
    return crc;

}

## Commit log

2025-02-25 Fixing time stamping (#3)
    * Fixing time stamping
    * Fixing timestamping and code cleanup
    * Update arduino code
    [transponder.ino]
2025-04-24 Autogenerated from nv3 (#7)
    * add a transponder to lla node
    * network debugging (#8)
    * debugging script
    * Comment debugging code for now
    * Feedback using the car mode
    * Updates to arduino code
    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
2025-04-29 Nv3 (#10)
    * Adding heading into the transponder message (#9)
    * Adding heading into the transponder message
    * Update Transponder.msg
    * Remove dependencies on CAST Racer code, but keep examples
    ---------
    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
2025-06-29 Better documentation (#13)
    * Better documentation
    * Adding cad stuff
    * Updated stl files
    * Updated stl files
    [2.4GHz_antenna_long.SLDPRT, M3x6.SLDPRT, esp32-poe-iso_mount.SLDPRT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]
2025-07-03 adding correct car 7 ip
    [transponder.ino]
2025-07-08 Disable debug prints unless explicity activated
